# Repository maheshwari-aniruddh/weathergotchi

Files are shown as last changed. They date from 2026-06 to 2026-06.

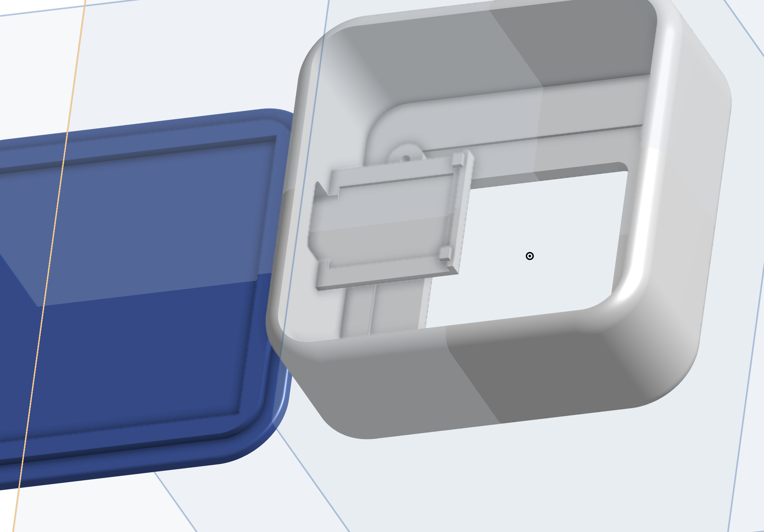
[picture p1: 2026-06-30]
Screenshot 2026-06-30 at 10.26.45 PM.png

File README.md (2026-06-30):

This is a weathergotchi or a pocket weather deviec, its a device that stays always on and shows you the weather, its super simple, it will have a oled screen on the front that uses the wifi on the esp32 to conect to the interent, call an weather api and show you the waether of your location.

To set it up, i will have it show a qr code on its screen that links to an external web page where you can put in the login info for the wifi.

To assemle it, we must screw in the screen with the included screws and then solder the wires from the esp32 to the screen and also connect the battery with the jst connector

here is the link to the onshape: https://cad.onshape.com/documents/1b819b621bfca7a87a20b835/w/54679f0c98fa81d0c5295e66/e/551f97a1be8f056300e5fcad





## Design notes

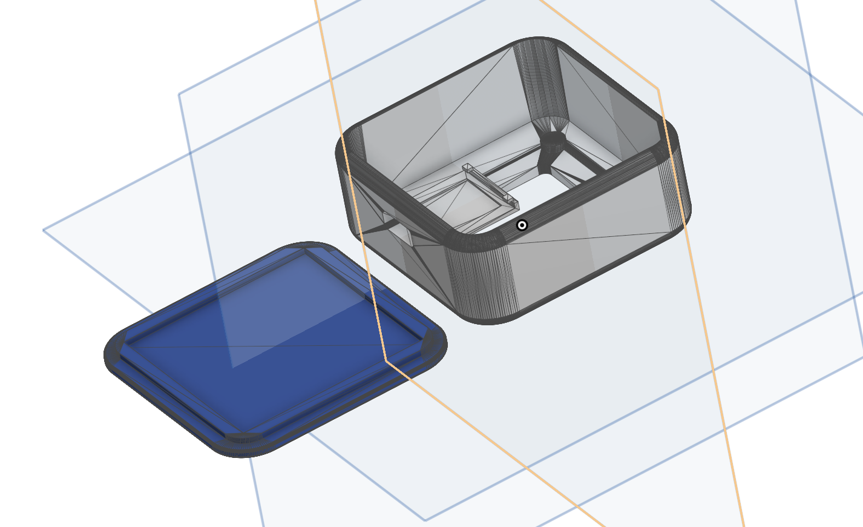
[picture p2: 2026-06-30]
Screenshot 2026-06-30 at 10.25.50 PM.png

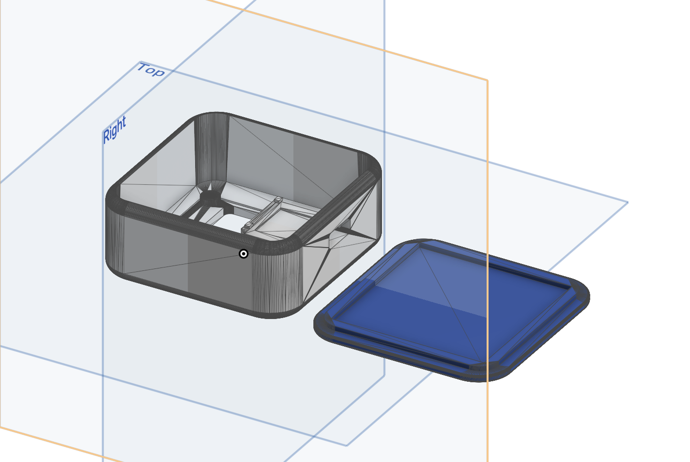
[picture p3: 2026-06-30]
Screenshot 2026-06-30 at 10.25.45 PM.png

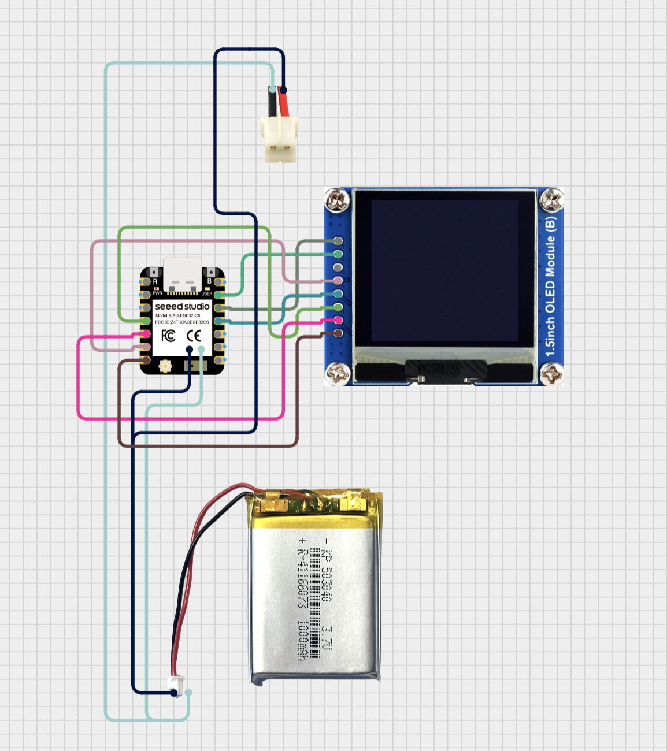
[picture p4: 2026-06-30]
Screenshot 2026-06-27 at 11.59.40 PM.png

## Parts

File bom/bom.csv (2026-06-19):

Item | Description | Qty | Unit Price (INR | shipping+tax included) | Unit Price (USD approx) | Seller | Product Link | Notes
LiPo Battery 3.7V 2000mAh (KP-603048) | 2-pin connector, lithium polymer, KP Original | 1 | 397.00 | 4.21 | Amazon.in | https://www.amazon.in/KP-Original-Battery-Rechargeable-KP-603048/dp/B0GM6RKSB4 | Free Prime delivery (shipping already included). Bought together with row below in same cart.
JST-PH 2.0mm 2-Pin Connector Set (Villcron) | Female pre-wired socket + loose male plug for Li-ion battery wiring | 1 | 79.00 | 0.84 | Amazon.in | https://www.amazon.in/VillcronTM-Connector-Silicone-Battery-Electronics/dp/B0GPQMHPRS | Free Prime delivery (shipping already included). Same cart as row above - combined subtotal was 476.00.
Waveshare 1.5inch RGB OLED Display Module (SKU 14747) | 65K RGB colors, 128x128, SPI, SSD1351 driver | 1 | 1550.00 | 16.43 | Hubtronics.in | https://hubtronics.in/1.5inch-rgb-oled-module | Price with 18% IGST + shipping applied (pre-tax unit price 1250.00 + 75.00 shipping = 1550.00 to pay). High-confidence match: exact title + exact pre-tax price match your screenshot.
Seeed Studio XIAO ESP32C6 | MCU board with onboard WiFi 6 / BLE | 1 | 844.99 | 8.96 | ThinkRobotics.com | https://thinkrobotics.com/products/xiao-esp32c6 | Subtotal 749.99 + shipping 95.00 = 844.99, incl 114.41 tax, matches your screenshot's numbers and checkout UI (Shopify).
TOTAL |  |  | 2870.99 | 30.43 |  |  | Sum of shipping-included unit prices above. USD at ~94.33 INR/USD (today's mid-market rate, fees not included).

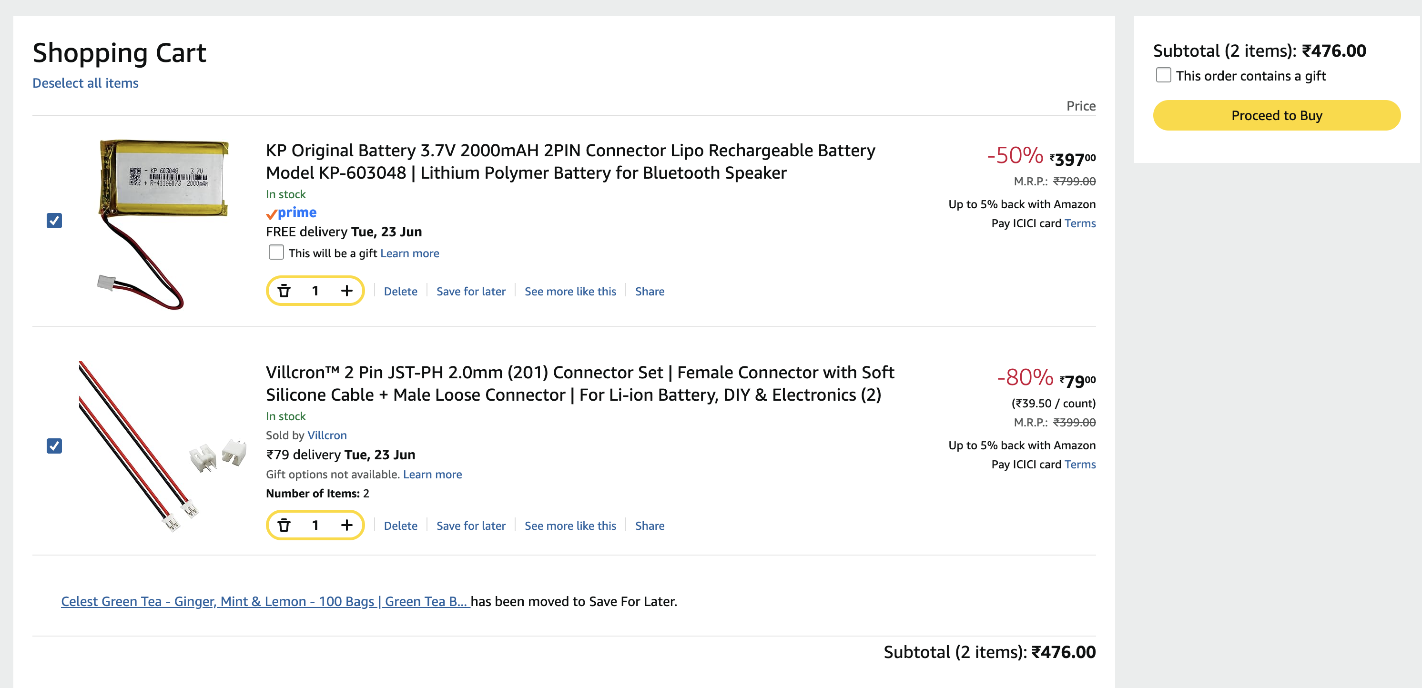
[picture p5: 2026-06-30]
bom/battery-kp603048-and-connector.png

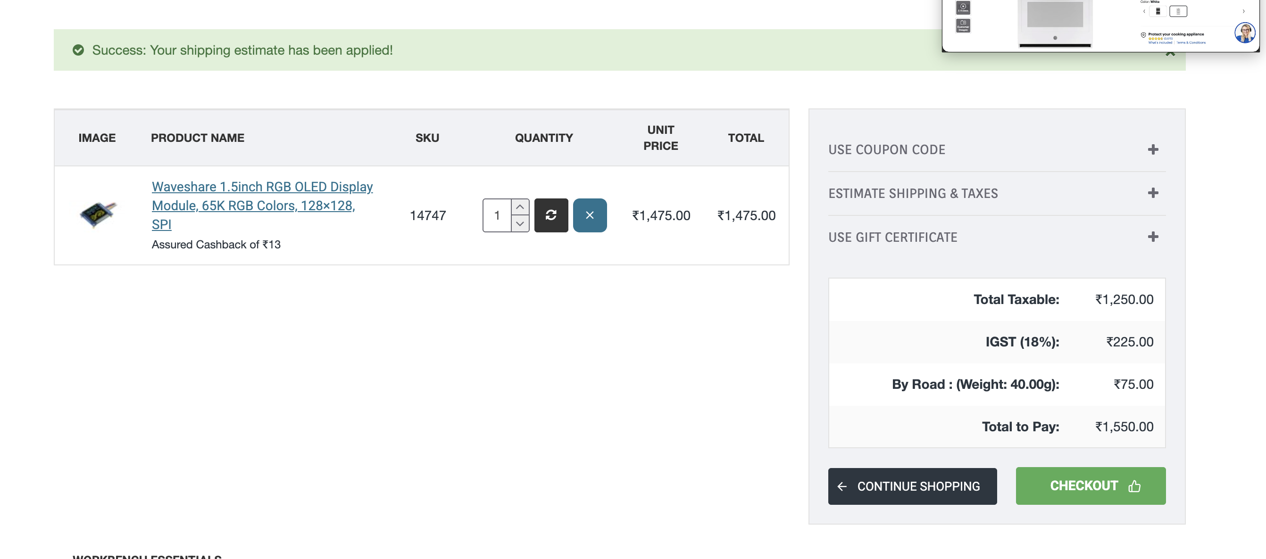
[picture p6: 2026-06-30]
bom/oled-waveshare-1.5in-128x128.png

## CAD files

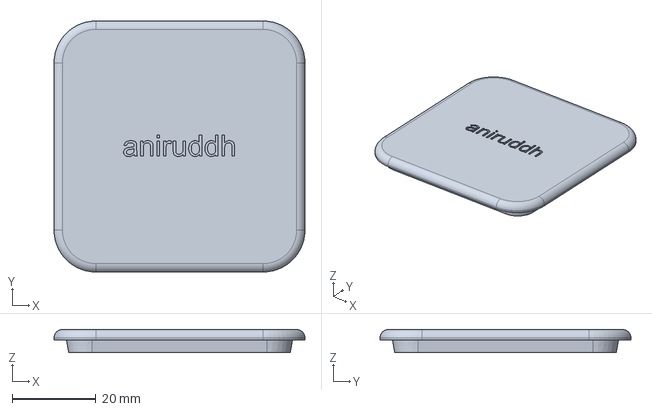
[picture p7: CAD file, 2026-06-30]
enclosure/enclosure_v5_lid.step
60.0 x 60.0 x 5.50 mm

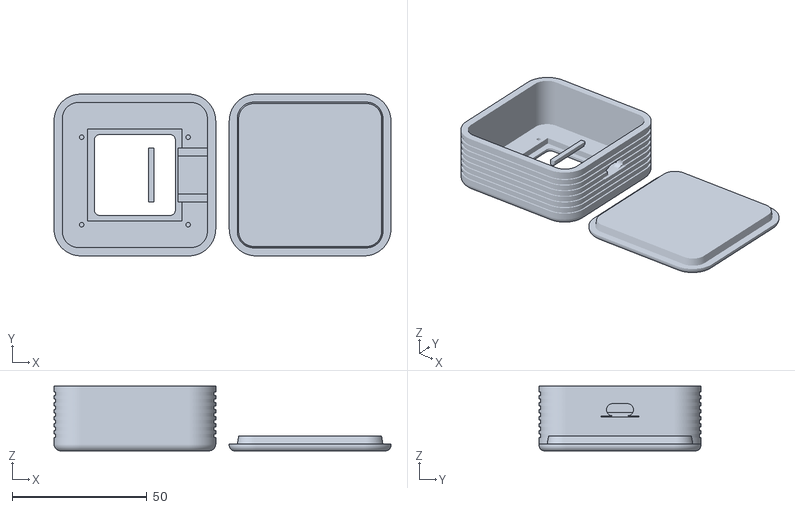
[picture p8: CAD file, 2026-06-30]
enclosure/enclosure_v5_combined.stl
125.0 x 60.0 x 24.0

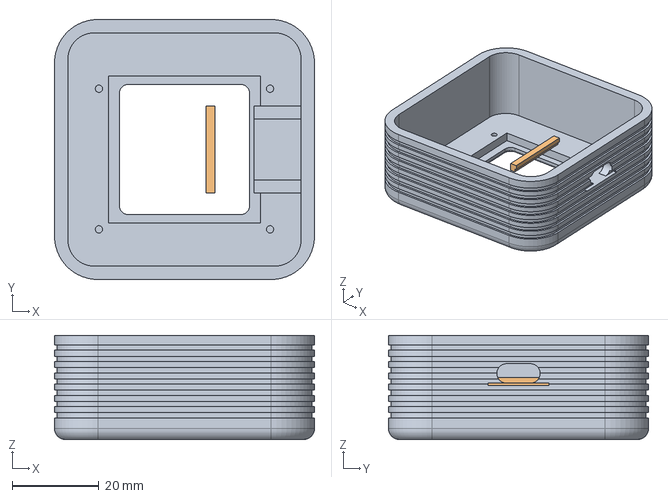
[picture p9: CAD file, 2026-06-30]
enclosure/enclosure_v5_body.step
60.0 x 60.0 x 24.0 mm

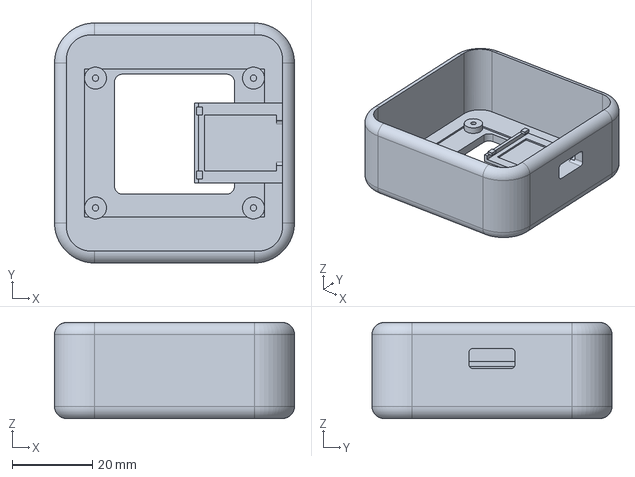
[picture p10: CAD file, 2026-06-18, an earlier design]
enclosure/enclosure_v4_body.step
60.0 x 60.0 x 24.0 mm

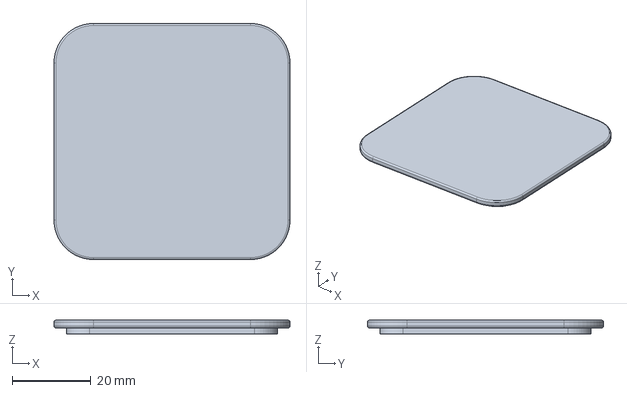
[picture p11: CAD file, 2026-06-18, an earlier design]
enclosure/enclosure_v4_lid.step
60.0 x 60.0 x 3.50 mm

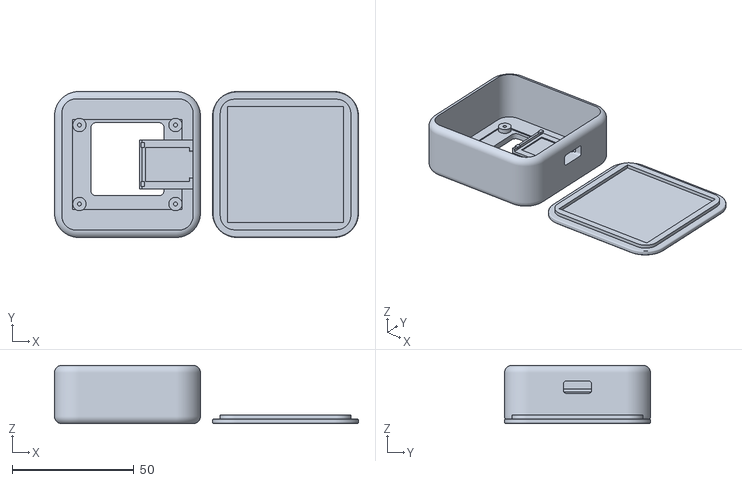
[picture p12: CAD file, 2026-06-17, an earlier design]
enclosure/enclosure_v4_combined.stl
125.0 x 60.0 x 24.0

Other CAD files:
enclosure/enclosure_v4_body.stl
enclosure/enclosure_v4_lid.stl
enclosure/enclosure_v5_body.stl
enclosure/enclosure_v5_lid.stl

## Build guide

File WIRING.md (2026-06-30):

# WeatherGotchi — Wiring

Board: **Seeed Studio XIAO ESP32-C6**
Display: **Waveshare 1.5" RGB OLED (SSD1351, 128×128, SPI)**
Battery: **KP-603048 3.7V 2000 mAh LiPo (JST-PH 2.0, 2-pin)**

Pins match `WeatherGotchi/config.h`. The XIAO only breaks out GPIO
2,3,4,5,6,7,8,9,10,20,21 — these all use the silkscreen pad labels.

## OLED (SPI) → XIAO

| OLED pad | Wire | XIAO pad | GPIO | config.h |
|---|---|---|---|---|
| VCC | red | **3V3**  | — | (power) |
| GND | black  | **GND**  | — | (power) |
| DIN (MOSI) | blue | **D10**  | 10 | `OLED_MOSI` |
| CLK (SCK) | yellow | **D8** | 8 | `OLED_SCK`  |
| CS | orange | **D7** | 20 | `OLED_CS` |
| DC | green  | **D6** | 21 | `OLED_DC` |
| RST | white  | **D0** | 2 | `OLED_RST`  |

> The SSD1351 module runs at 3.3 V logic — drive it from **3V3**, not 5V.

## Button (optional) → XIAO

| Button | XIAO pad | GPIO | config.h |
|---|---|---|---|
| leg A  | **D1** | 3 | `BUTTON_PIN` |
| leg B  | **GND**  | — | — |

Active-low with the internal pull-up. Short press = next screen, long press
(~1 s) = force a weather refresh.

## Battery → XIAO (underside BAT pads)

| LiPo wire | XIAO pad |
|---|---|
| red  (+)  | **BAT+** |
| black (−) | **BAT−** |

The XIAO charges the LiPo over its USB-C port automatically. **Check polarity
with a multimeter before plugging the JST in** — connector wiring is not
guaranteed, and reversed polarity can destroy the board.

> Battery % is *estimated from runtime*, not measured — there's no voltage
> divider wired. See the battery notes in `config.h`.

## Charge Detect (optional, currently OFF)

| Signal | XIAO pad | GPIO | config.h |
|---|---|---|---|
| USB presence (optional) | **A2** | 4 | `CHARGE_DETECT_PIN` |

If you wire a USB-presence detector (e.g., a resistor divider on the USB 5V line), connect it to A2. Set `USE_CHARGE_DETECT 1` to enable. Currently disabled (`USE_CHARGE_DETECT 0`).

## Diagram

```
                Waveshare 1.5" OLED (SSD1351)
              +-----------------------------------+
              | VCC GND DIN CLK CS  DC  RST       |
              +--+---+---+---+---+---+---+---------+
                 |   |   |   |   |   |   |
   3V3 ----------+   |   |   |   |   |   |
   GND --------------+   |   |   |   |   |
   D10 (GPIO10) MOSI-----+   |   |   |   |
   D8  (GPIO8)  SCK ---------+   |   |   |
   D7  (GPIO20) CS --------------+   |   |
   D6  (GPIO21) DC ------------------+   |
   D0  (GPIO2)  RST ---------------------+

          Seeed XIAO ESP32-C6
        +-----------------------+
   USB-C|()                     |
        |  D0  D1  D2 ... 3V3   |
        |  D6  D7  D8  D9  D10  |
        +----+--------------+---+
             |              |
   Button:   D1 ---[ btn ]--- GND
                              (GPIO3, internal pull-up)

        Underside:  BAT+ o---(red)---  LiPo +
                    BAT- o---(black)-- LiPo -
```

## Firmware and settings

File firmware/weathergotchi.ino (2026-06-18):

#include <Wifi.h>
#include <HWifiManager.h>
#include <time.h>
#include <config.h>
#include <weather.h>
#include <ui.h>

UIManager ui;
WeatherManager weather;
WeatherData weatherData;
WifiManager wm;

unsigned long lastWeatherUpdate = 0;
int simulatedBatteryPct = 78;
unsigned long lastBatterIncrementTime = 0;

const char* ntpServer = "pool.ntp.org";
const long gmtOffset_sec = 0;
const int daylightOffset_sec = 3600;

void configModeCallback (WifiManager *myWifiMananger)
{
    Serial.println("WifiManager entered config mode");
    Serial.println("Access Point SSID:");
    Serial.println(myWifiMananger->getConfigPortalSSID());
    Serial.println("IP address:");
    Serial.println(WiFi.softAPIP());

    ui.drawWifiQR(myWifiMananger->getConfigPortalSSID());
}


String getFormattedTime(){
    struct tm timeinfo;
    if(!getLocalTime(&timeinfo))
    {
        return "--:--";
    }
    char timeStr[6];
    strftime(timeStr, sizeof(timeStr), "%H:%M", &timeinfo);
    return String(timeStr);
}

void setup()
{
    Serial.begin(115200);
    delay(1000);
    Serial.println("Starting WeatherGotchi...");

    ui.begin();
    ui.drawMessage("Weather Gotchi","Starting up...",COLOR_CYAN);
    delay(1500);

    pinMode(CHARGE_DETECT_PIN,INPUT);

    wm.setAPCallback(configModeCallback);

    ui.drawMessage("Wifi Setup","Checking connection...",COLOR.WHITE);
    if(!wm.autoConnect(WIFI_AP_SSID))
    {
        Serial.println("Failed to connect and hit timeout");
        ui.drawMessage("Connection Error","Rebooting...",COLOR_RED);
        delay(3000);
        ESP.restart();
    }

    Serial.println("Connected to WiFi");
    ui.drawMessage("Wifi Connected","Initializing time...",COLOR_GREEN);

    configTime(gmtOffset_sec, daylightOffset_sec, ntpServer);

    setenv("TZ","PST8PDT,M3.2.0,M11.1.0",1);
    tzset();

    ui.drawMessage("Fetching Weather","Downloading data...",COLOR_CYAN  );
    if(weather.updateWeather(weatherData))
    {
        lastWeatherUpdate = millis();
    }
    else
    {
        ui.drawMessage("Error","Weather Fetch Failed",COLOR_RED);
        delay(2000);
    }
}


void loop()
{
    int chargeSensorVal = analogRead(CHARGE_DETECT_PIN);
    bool isCharging = (chargeSensorVal>1000)

    if(isCharging)
    {
        unsigned long currentMillis = millis();

        if(currentMillis - lastBatteryIncrementTime>=60000)
        {
            simulatedBatteryPct++;
            if(simulatedBatteryPct>100)
            {
                simulatedBatteryPct = 100;
            }
            lastBatteryIncrementTime = currentMillis;
        }
        ui.drawChargingScreen(0,simulatedBatteryPct);
        delay(33);
    }
    else
    {
        bool isConnected = (WiFi.status() == WL_CONNECTED);

        unsigned long currentMillis = millis();
        if(currentMillis - lastWeatherUpdate>= WEATHER_REFRESH_INTERVAL)
        {
            Serial.println("Hourly update interval reached. Refreshing weather..."};
            if(!isConnected)
            {
                Serial.println("Wifi Disconnected. Attempting to reconnect...")l;
                Wifi.begin();
                itn retries = 0;
                while(Wifi.status() != WL_CONNECTED && retries < 15)
                {
                    delay(500);
                    retries++;
                }
                isConnected = (WiFi.status() == WL_CONNECTED);
            }
            if(isConnected)
            {
                if(weather.updateWeather(weatherData))
                {
                    lastWeatherUpdate = currentMillis;
                }
            }
    

        String timeStr = getFormattedTime();
        ui.drawDashboard(weatherData,timeStr,100,isConnected);

        delay(33);
    }
}

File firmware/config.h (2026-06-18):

#ifndef CONFIG_H
#define CONFIG_H

#include <Arduino.h>

#define SCREEN_WIDTH 128
#define SCREEN_HEIGHT 128     

#define OLED_MOSI 15
#define OLED_SCK 13
#define OLED_CS 2
#define OLED_DC 16
#define OLED_RST 3

#define CHARGE_DETECT_PIN A0
#define CHARGE_THERESHOLD 1500

#define GEOLOCATION_URL "http://ip-api.com/json"
#define WEATHER_API_BASE "http://api.open-meteo.com/v1/forecast"

#define WEATHER_REFRESH_INTERVAL 3600000 // 1 hour in milliseconds
#define WIFI_AP_SSID "YourWiFiSSID"

#define COLOR_BLACK 0x0000
#define COLOR_WHITE 0xFFFF
#define COLOR_RED 0xF800
#define COLOR_GREEN 0x07E0
#define COLOR_BLUE 0x001F
#define COLOR_CYAN 0x07FF
#define COLOR_YELLOW 0xFFE0
#define COLOR_GREY 0x7BEF


#endif // CONFIG_H

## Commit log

2026-06-17 feat: add v4 enclosure body, lid, and combined STL models for 3D printing
    [enclosure_v4_body.stl, enclosure_v4_combined.stl, enclosure_v4_lid.stl]
2026-06-19 started work on the ui page but also i have added the bom
    [bom.csv]
2026-06-20 tightned the lid and made thehwole wall thick instead of adding posts
    [enclosure_v5_body.step, enclosure_v5_body.stl, enclosure_v5_combined.stl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]
2026-06-30 added a proper readme
    [enclosure_v4_body.stl, enclosure_v4_combined.stl, enclosure_v4_lid.step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]
2026-06-30 readme added
    [bom.csv, enclosure_v4_body.step, enclosure_v5_body.step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]
